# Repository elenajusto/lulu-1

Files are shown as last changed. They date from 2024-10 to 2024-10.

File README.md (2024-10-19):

# lulu-1

# Mechanical
## Open Rocket View


## Physical Fully Assembled


# Electronic

## PCB Design 

### Architecture


### PCB Schematic 


## Perfboard Prototyping


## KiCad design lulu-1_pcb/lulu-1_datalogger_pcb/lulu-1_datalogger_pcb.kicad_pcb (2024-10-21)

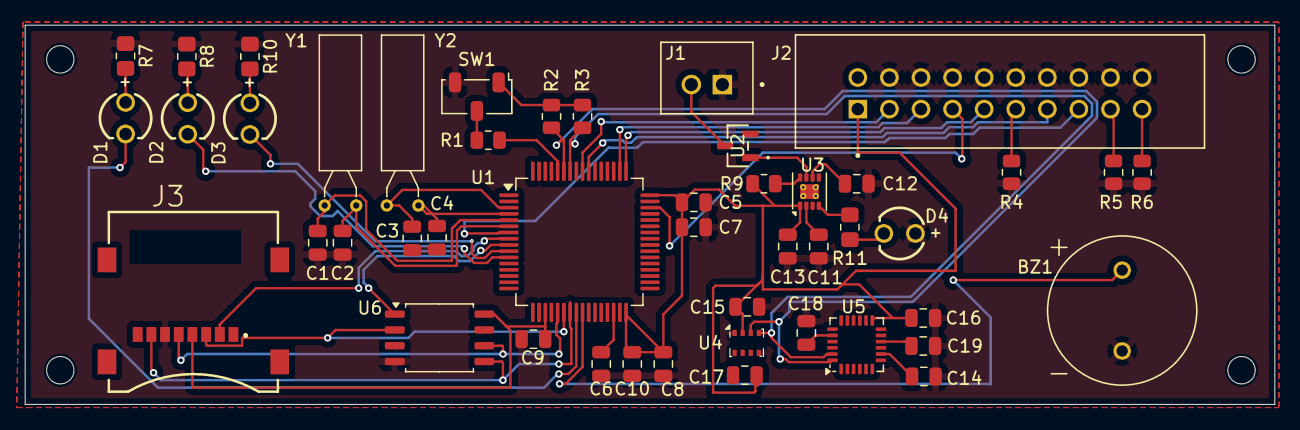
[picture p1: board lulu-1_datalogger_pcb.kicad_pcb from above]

Board: 2 copper layers, 100.5 x 30.5 mm, 47 parts (0 on the bottom side), 39 nets.

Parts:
BZ1: Buzzer; XDCR_AT-1224-TWT-5V-2-R
C1, C2: 20pF; C_0805_2012Metric
C3, C4: 1.5pF; C_0805_2012Metric
C5, C7, C8, C9: 100 nF; C_0805_2012Metric
C6, C11, C13: 2.2uF; C_0805_2012Metric
C10, C14: 10nF; C_0805_2012Metric
C12: 33nF; C_0805_2012Metric
C15, C17: 100nf; C_0805_2012Metric
C16, C19: 0.1uF; C_0805_2012Metric
C18: 2.2nF; C_0805_2012Metric
D1, D2, D3, D4: LED; WL-TMRC_3MM
J1: B2B-XH-A; JST_B2B-XH-A
J2: SBH11-PBPC-D10-ST-BK; SULLINS_SBH11-PBPC-D10-ST-BK
J3: MEM2067-02-180-00-A_REVB; GCT_MEM2067-02-180-00-A_REVB
R1, R3: 10k; R_0805_2012Metric
R2, R4, R5, R6: 10K; R_0805_2012Metric
R7, R8, R10, R11: 100Ω; R_0805_2012Metric_Pad1.20x1.40mm_HandSolder
R9: 100k; R_0805_2012Metric
SW1: SW_Nidec_CAS-120A1; Nidec_Copal_CAS-120A
U1: STM32F401RETx; LQFP-64_10x10mm_P0.5mm
U2: BAT54LT1G; SOT-23-3_1P4X3P040_ONS
U3: LP3982ILD-3.3; WSON-8-1EP_3x2.5mm_P0.5mm_EP1.2x1.5mm_PullBack_ThermalVias
U4: BMP280; Bosch_LGA-8_2x2.5mm_P0.65mm_ClockwisePinNumbering
U5: MPU-6050; InvenSense_QFN-24_4x4mm_P0.5mm
U6: W25Q16JVSS; SOIC-8_5.23x5.23mm_P1.27mm
Y1: 25 Mhz; Crystal_AT310_D3.0mm_L10.0mm_Horizontal
Y2: 32 Khz; Crystal_AT310_D3.0mm_L10.0mm_Horizontal

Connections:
+3.3V: R2.2, R3.2, SW1.1 (C)
+3V3: C5.2, C7.2, C8.2, C9.2, C10.2, C13.1, C14.2, C15.2, C16.1, C17.2, J2.1, J2.2, J3.4 (VDD), R9.2, R11.1, U1.1 (VBAT), U1.19 (VDD), U1.32 (VDD), U1.48 (VDD), U1.64 (VDD), U3.1 (OUT), U3.4 (OUT), U4.2 (CSB), U4.6 (VDDIO), U4.8 (VDD), U5.8 (VLOGIC), U5.13 (VDD), U6.8 (VCC)
BUZZ: BZ1.P, U1.25 (PC5)
CS_FLASH: U1.9 (PC1), U6.1 (~CS)
CS_SD: J3.2 (CD/DAT3), U1.8 (PC0)
GND: BZ1.N, C1.1, C2.1, C3.1, C4.1, C5.1, C6.1, C7.1, C8.1, C9.1, C10.1, C11.2, C12.2, C13.2, C14.1, C15.1, C16.2, C17.1, C18.1, C19.2, D4.1 (K), J1.1, J2.4, J2.6, J2.8, J2.10, J2.12, J2.14, J2.16, J2.18, J2.20, J3.6 (VSS), R4.1, R5.1, R6.1, R7.1, R8.1, R10.1, SW1.3 (A), U1.12 (VSSA), U1.18 (VSS), U1.31 (VSS), U1.47 (VSS), U1.63 (VSS), U3.3 (GND), U4.1 (GND), U4.5 (SDO), U4.7 (GND), U5.18 (GND), U6.4 (GND)
JTCK_SWCLK: J2.9, U1.49 (PA14)
JTDI: J2.5, U1.50 (PA15)
JTDO_SWO: J2.13, U1.55 (PB3)
JTMS_SWDIO: J2.7, U1.46 (PA13)
JTRST: J2.3, U1.56 (PB4)
LED1: D3.2 (A), U1.10 (PC2)
LED2: D2.2 (A), U1.11 (PC3)
LED3: D1.2 (A), U1.24 (PC4)
NRST: J2.15, U1.7 (NRST)
unnamed: D1.1 (K), R7.2
unnamed: D2.1 (K), R8.2
unnamed: D3.1 (K), R10.2
unnamed: D4.2 (A), R11.2
unnamed: J2.11, R4.2
unnamed: J2.17, R5.2
unnamed: J2.19, R6.2
unnamed: R1.1, SW1.2 (B)
unnamed: R1.2, U1.60 (BOOT0)
unnamed: C3.2, U1.3 (PC14), Y2.2
unnamed: C4.2, U1.4 (PC15), Y2.1
unnamed: C1.2, U1.5 (PH0), Y1.2
unnamed: C2.2, U1.6 (PH1), Y1.1
unnamed: C6.2, U1.30 (VCAP1)
unnamed: C12.1, U3.6 (CC)
unnamed: R9.1, U3.8 (~FAULT)
unnamed: C18.2, U5.20 (CPOUT)
unnamed: C19.1, U5.10 (REGOUT)
PB6: R3.1, U1.58 (PB6), U4.4 (SCK), U5.23 (SCL)
PB7: R2.1, U1.59 (PB7), U4.3 (SDI), U5.24 (SDA)
SP1_MISO: J3.3 (CMD), U1.22 (PA6), U6.2 (DO(IO1))
SP1_MOSI: J3.7 (DAT0), U1.23 (PA7), U6.5 (DI(IO0))
SP1_SCK: J3.5 (CLK), U1.21 (PA5), U6.6 (CLK)
VBUS: C11.1, J1.2, U2.1 (ANODE), U2.3 (CATHODE), U3.2 (IN), U3.7 (~SHDN)

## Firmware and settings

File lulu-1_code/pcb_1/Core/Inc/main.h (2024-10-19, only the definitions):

#define CS_SD_Pin GPIO_PIN_0
#define CS_SD_GPIO_Port GPIOC
#define CS_FLASH_Pin GPIO_PIN_1
#define CS_FLASH_GPIO_Port GPIOC
#define GPIO_LED1_Pin GPIO_PIN_2
#define GPIO_LED1_GPIO_Port GPIOC
#define GPIO_LED2_Pin GPIO_PIN_3
#define GPIO_LED2_GPIO_Port GPIOC
#define GPIO_LED3_Pin GPIO_PIN_4
#define GPIO_LED3_GPIO_Port GPIOC
#define GPIO_BUZZ_Pin GPIO_PIN_5
#define GPIO_BUZZ_GPIO_Port GPIOC

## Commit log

2024-10-08 first iteration of datalogger pcb
    [lulu-1_datalogger_pcb.kicad_pcb, lulu-1_datalogger_pcb.kicad_sch]
2024-10-08 initialised stm32 project. initialised pinouts
2024-10-08 remove metadata from stm32 from tracking
2024-10-08 removed .settings from stm32 from tracking
2024-10-08 deleted project
    [lulu-1_datalogger_pcb.kicad_sch]
2024-10-08 reinit stm32 project
2024-10-08 initialised pins for SPI CS and added on schematic
    [lulu-1_datalogger_pcb.kicad_sch]
2024-10-08 decoupling capactirs to i2c components as per datasheets
    [lulu-1_datalogger_pcb.kicad_sch]
2024-10-09 changed MOSI and MISO connection for flash chiP
    [lulu-1_datalogger_pcb.kicad_sch]
2024-10-09 added 0805 footprints for resistors and capacitors
    [lulu-1_datalogger_pcb.kicad_sch]
2024-10-09 updated openrocket values for avionics
    [lulu-1_datalogger_pcb.kicad_pcb, lulu-1_datalogger_pcb.kicad_sch]
2024-10-15 Replaced footprint and symbol for USB with part that i am ordering
    [lulu-1_datalogger_pcb.kicad_pcb, lulu-1_datalogger_pcb.kicad_sch]
2024-10-15 tidy circuit
    [lulu-1_datalogger_pcb.kicad_sch]
2024-10-15 more tidying
    [lulu-1_datalogger_pcb.kicad_sch]
2024-10-18 imported and added hinged sd card with footprint
    [lulu-1_datalogger_pcb.kicad_sch]
2024-10-18 removed usb-c from schematic
    [lulu-1_datalogger_pcb.kicad_sch]
2024-10-18 re-imported JTAG connector with symbol and footprint from manufacturer
    [lulu-1_datalogger_pcb.kicad_sch]
2024-10-18 reannotated schematic
    [lulu-1_datalogger_pcb.kicad_sch]
2024-10-18 reorgansed schematic to be more cleaner
    [lulu-1_datalogger_pcb.kicad_sch]
2024-10-18 label for SPI chip select pins and remvoed VBAT and merged with +3V3/VDD pins
    [lulu-1_datalogger_pcb.kicad_sch]
2024-10-18 added reverse polarity protection diode
    [lulu-1_datalogger_pcb.kicad_sch]
2024-10-18 added JST-XH connector for 18650 LiIon battery
    [lulu-1_datalogger_pcb.kicad_sch]
2024-10-19 removed usb bus pins from mcu
    [lulu-1_datalogger_pcb.kicad_pcb, lulu-1_datalogger_pcb.kicad_sch]
2024-10-19 added continuity LED to voltage regulator output
    [lulu-1_datalogger_pcb.kicad_sch]
2024-10-19 added programmable LEDs and buzzer to schematic and to .ioc file
    [lulu-1_datalogger_pcb.kicad_sch]
2024-10-19 assigned footprints to indictors
    [lulu-1_datalogger_pcb.kicad_sch]
2024-10-19 assigned footprint to continuity led
    [lulu-1_datalogger_pcb.kicad_sch]
2024-10-19 fixed LED polarity on schematic
    [lulu-1_datalogger_pcb.kicad_pcb, lulu-1_datalogger_pcb.kicad_sch]
2024-10-19 initial pcb layout
    [lulu-1_datalogger_pcb.kicad_pcb]
2024-10-19 added mounting holes
    [lulu-1_datalogger_pcb.kicad_pcb, lulu-1_datalogger_pcb.kicad_sch]
2024-10-21 finished initial traces. however errors in DRC to be resolved
    [lulu-1_datalogger_pcb.kicad_pcb, lulu-1_datalogger_pcb.kicad_sch]
2024-10-21 changed clearance to 0.15mm
    [lulu-1_datalogger_pcb.kicad_pcb]

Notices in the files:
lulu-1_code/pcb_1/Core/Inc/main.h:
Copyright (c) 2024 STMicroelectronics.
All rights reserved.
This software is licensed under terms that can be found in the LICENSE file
